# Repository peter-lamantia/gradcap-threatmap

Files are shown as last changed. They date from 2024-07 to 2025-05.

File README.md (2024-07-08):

# Graduation Cap Live Threat Map PCB

## About

This is a pet project to learn more about microcontroller development and PCB design.

My plan is to: 
1. Reverse engineer the Fortinet WebSocket API
2. Program an ESP32 to connect to said API and log messages to serial
3. Design a PCB with:
   - an ESP32-S3
   - a world map graphic and WS2812B LEDs placed at key cities
   - a lithium battery and charging circuit
   - dimensions that will place it neatly on a graduation cap
   - a display to show the attack details
4. Program the ESP32 to parse the incoming WebSocket such that:
   - the longitudinal data will map to the closest physical LED on the board
   - the LED will light up with a certain color depending on the threat type
   - ideally, I can make the LEDs animated in a cool way

## Roadmap
- WiFi connection reestablishment
- WebSocket connection reestablishment
- An actual PCB to mess around with. It may be useful to do this in revisions, e.g. make a PCB with the LEDs first, write the software for that, then make a more capable PCB with all components. After all, it is my first time doing this.
- Figure out how to actually debug (not just print program state to serial!)

## Changelog

### 2024-07-07
- Full migration to Platform.io (it's great!)
- Started printing out threats to an OLED display
   - Used the U8g2 library, specifically [u8log](https://github.com/olikraus/u8g2/wiki/u8logreference) for display output
   - Parsed the JSON sent from the WebSocket using [ArduinoJSON](https://arduinojson.org/)
- Added and did some testing with [FastLED](https://github.com/FastLED/FastLED), but have not implemented it yet (it is likely best to wait until I've made the PCB)

### 2024-06-29 (initial commit)
- WiFi connection establishment
- WebSocket connection to Fortinet
- Prints WebSocket messages to serial

## Known issues/fixes
- If serial is enabled, the XIAO ESP32-S3 will not allow reflashing. To fix this, hold the boot button while powering it on, and then flash at will!

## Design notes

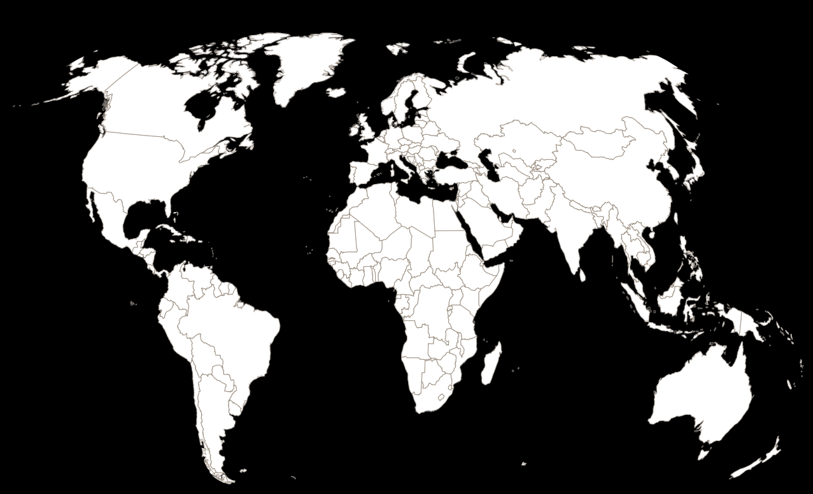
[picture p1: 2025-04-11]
pcb/winkel-tripel-no-antarctica.png

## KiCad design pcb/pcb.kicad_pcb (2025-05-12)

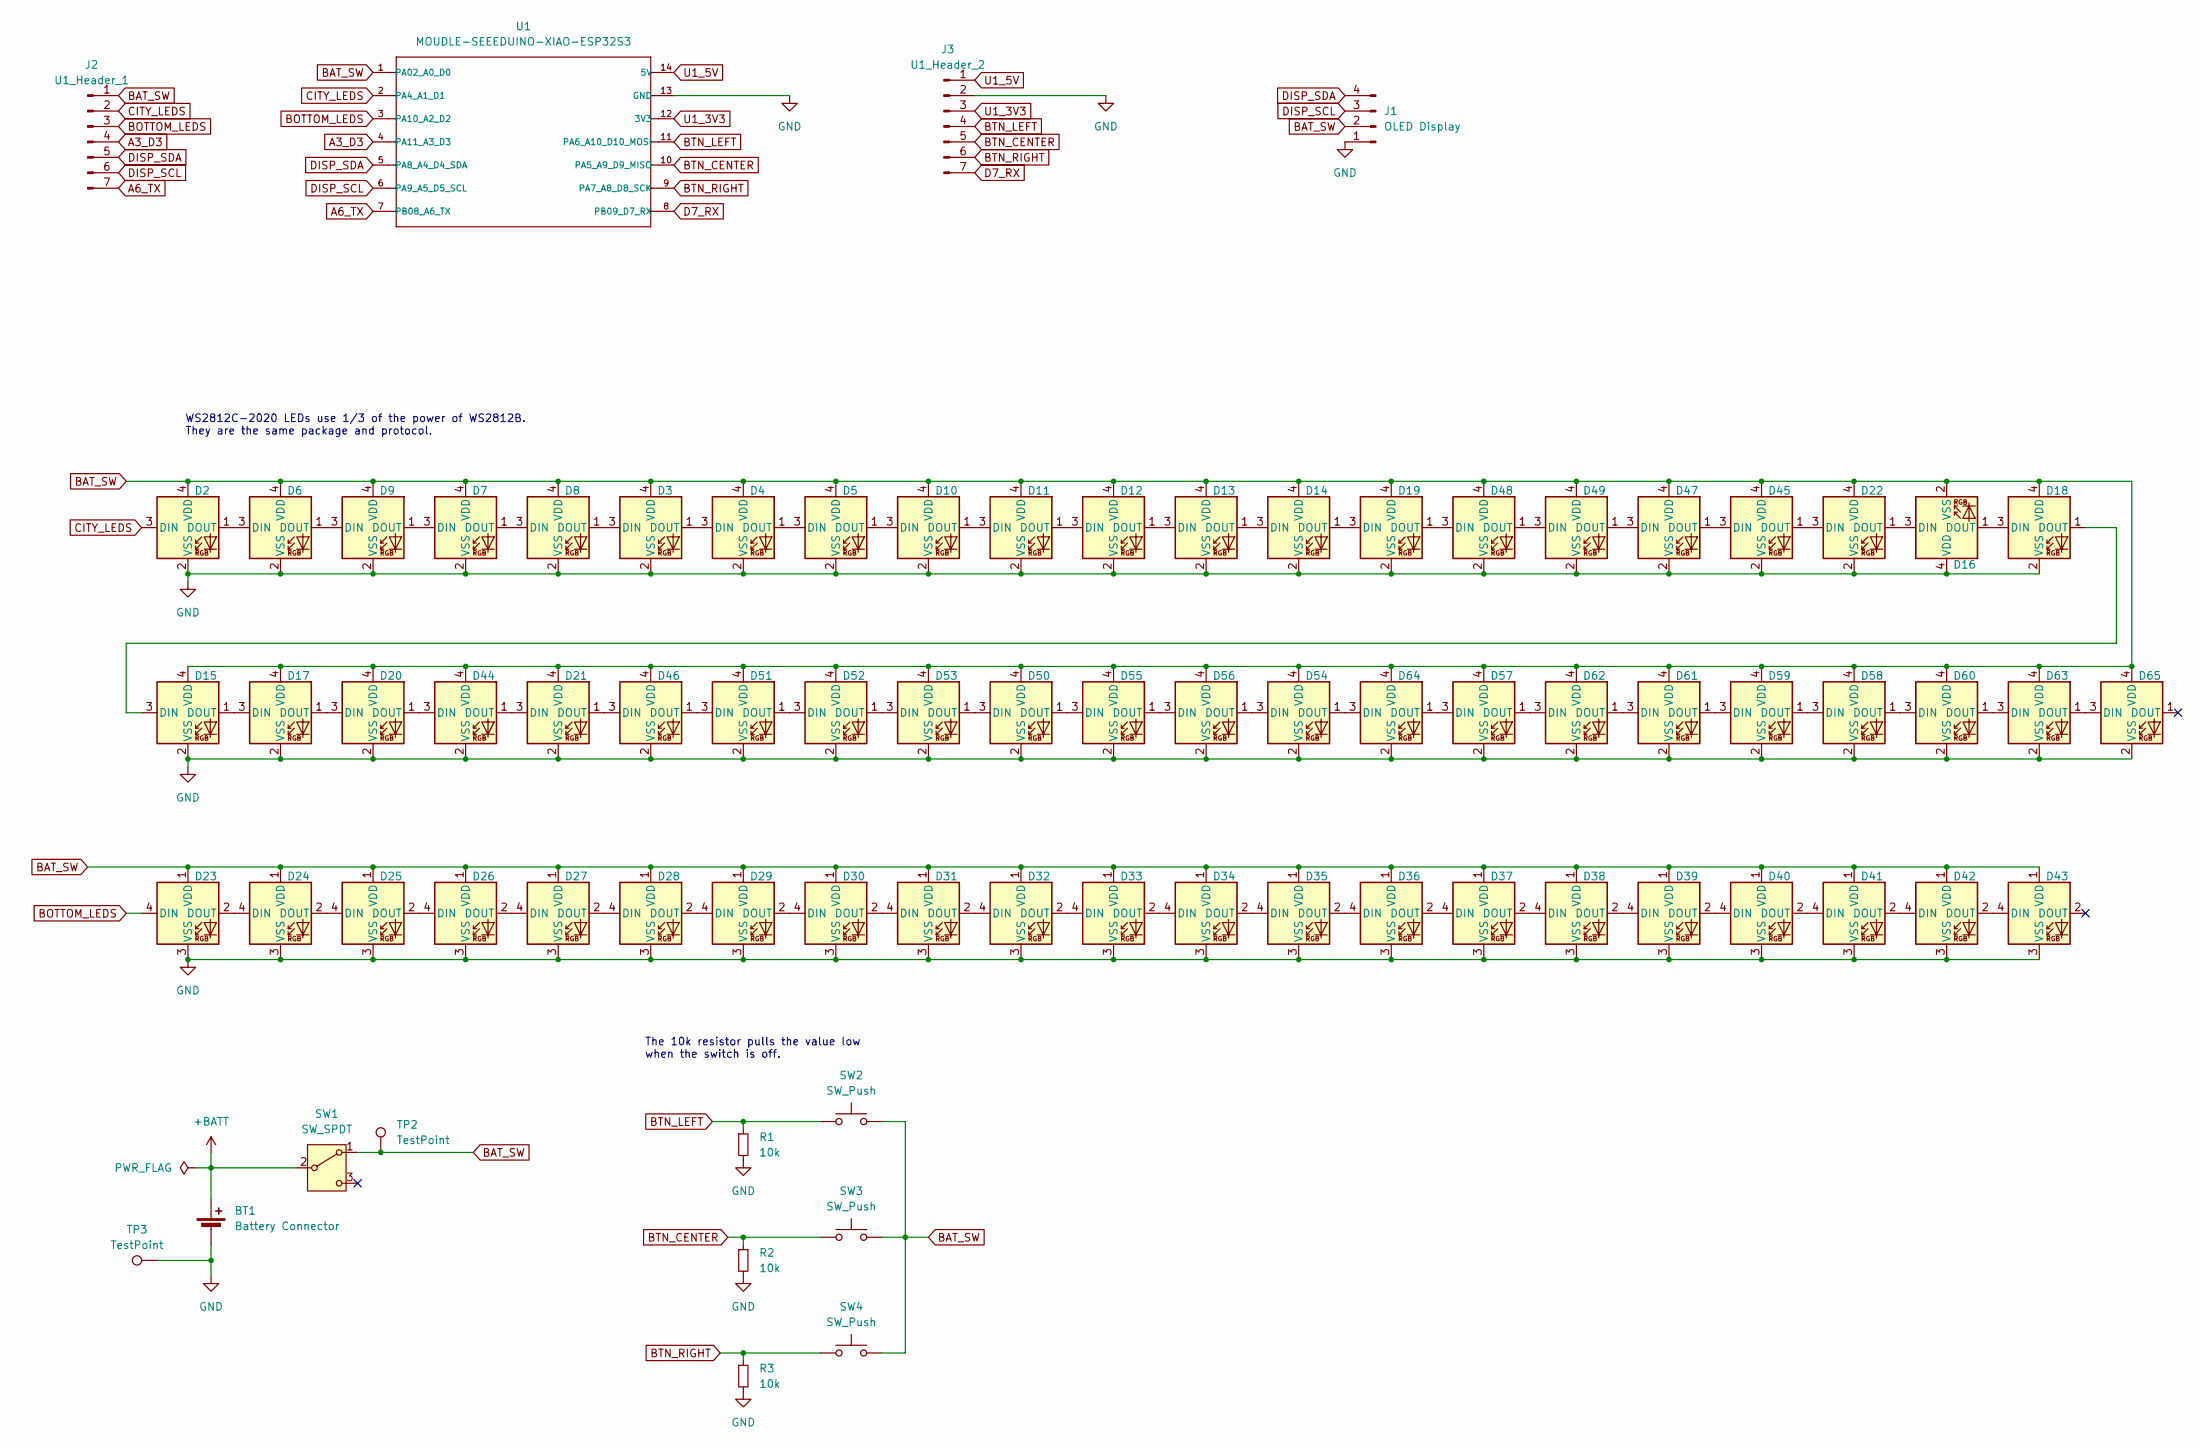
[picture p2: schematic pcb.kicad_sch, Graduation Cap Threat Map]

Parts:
BT1: Battery Connector; JST_PH_S2B-PH-K_1x02_P2.00mm_Horizontal
D2, D3, D4, D5, D6, D7, D8, D9, D10, D11, D12, D13, D14, D15, D16, D17, D18, D19, D20, D21, D22, D44, D45, D46, D47, D48, D49, D50, D51, D52, D53, D54, D55, D56, D57, D58, D59, D60, D61, D62, D63, D64, D65: WS2812C-2020; LED_WS2812B-2020_PLCC4_2.0x2.0mm
D23, D24, D25, D26, D27, D28, D29, D30, D31, D32, D33, D34, D35, D36, D37, D38, D39, D40, D41, D42, D43: WS2812C; LED_WS2812B_PLCC4_5.0x5.0mm_P3.2mm
J1: OLED Display; PinHeader_1x04_P2.54mm_Vertical
J2: U1_Header_1; PinSocket_1x07_P2.54mm_Vertical
J3: U1_Header_2; PinSocket_1x07_P2.54mm_Vertical
R1, R2, R3: 10k; R_Axial_DIN0207_L6.3mm_D2.5mm_P7.62mm_Horizontal
SW1: SW_SPDT; SW_Slide_SPDT_Angled_CK_OS102011MA1Q
SW2, SW3, SW4: SW_Push; SW_PUSH-12mm
TP2, TP3: TestPoint; TestPoint_Keystone_5015_Micro_Mini
U1: MOUDLE-SEEEDUINO-XIAO-ESP32S3; XIAO-ESP32S3-DIP

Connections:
+BATT: BT1.1 (+), SW1.2 (B)
A3_D3: J2.4, U1.4 (PA11_A3_D3)
A6_TX: J2.7, U1.7 (PB08_A6_TX)
BAT_SW: D2.4 (VDD), D3.4 (VDD), D4.4 (VDD), D5.4 (VDD), D6.4 (VDD), D7.4 (VDD), D8.4 (VDD), D9.4 (VDD), D10.4 (VDD), D11.4 (VDD), D12.4 (VDD), D13.4 (VDD), D14.4 (VDD), D15.4 (VDD), D16.2 (VSS), D17.4 (VDD), D18.4 (VDD), D19.4 (VDD), D20.4 (VDD), D21.4 (VDD), D22.4 (VDD), D23.1 (VDD), D24.1 (VDD), D25.1 (VDD), D26.1 (VDD), D27.1 (VDD), D28.1 (VDD), D29.1 (VDD), D30.1 (VDD), D31.1 (VDD), D32.1 (VDD), D33.1 (VDD), D34.1 (VDD), D35.1 (VDD), D36.1 (VDD), D37.1 (VDD), D38.1 (VDD), D39.1 (VDD), D40.1 (VDD), D41.1 (VDD), D42.1 (VDD), D43.1 (VDD), D44.4 (VDD), D45.4 (VDD), D46.4 (VDD), D47.4 (VDD), D48.4 (VDD), D49.4 (VDD), D50.4 (VDD), D51.4 (VDD), D52.4 (VDD), D53.4 (VDD), D54.4 (VDD), D55.4 (VDD), D56.4 (VDD), D57.4 (VDD), D58.4 (VDD), D59.4 (VDD), D60.4 (VDD), D61.4 (VDD), D62.4 (VDD), D63.4 (VDD), D64.4 (VDD), D65.4 (VDD), J1.2, J2.1, SW1.1 (A), SW2.2, SW3.2, SW4.2, TP2.1, U1.1 (PA02_A0_D0); also elsewhere on the board
BOTTOM_LEDS: D23.4 (DIN), J2.3, U1.3 (PA10_A2_D2)
BTN_CENTER: J3.5, R2.1, SW3.1, U1.10 (PA5_A9_D9_MISO)
BTN_LEFT: J3.4, R1.1, SW2.1, U1.11 (PA6_A10_D10_MOSI)
BTN_RIGHT: J3.6, R3.1, SW4.1, U1.9 (PA7_A8_D8_SCK)
CITY_LEDS: D2.3 (DIN), J2.2, U1.2 (PA4_A1_D1)
D7_RX: J3.7, U1.8 (PB09_D7_RX)
DISP_SCL: J1.3, J2.6, U1.6 (PA9_A5_D5_SCL)
DISP_SDA: J1.4, J2.5, U1.5 (PA8_A4_D4_SDA)
GND: BT1.2 (-), D2.2 (VSS), D3.2 (VSS), D4.2 (VSS), D5.2 (VSS), D6.2 (VSS), D7.2 (VSS), D8.2 (VSS), D9.2 (VSS), D10.2 (VSS), D11.2 (VSS), D12.2 (VSS), D13.2 (VSS), D14.2 (VSS), D15.2 (VSS), D16.4 (VDD), D17.2 (VSS), D18.2 (VSS), D19.2 (VSS), D20.2 (VSS), D21.2 (VSS), D22.2 (VSS), D23.3 (VSS), D24.3 (VSS), D25.3 (VSS), D26.3 (VSS), D27.3 (VSS), D28.3 (VSS), D29.3 (VSS), D30.3 (VSS), D31.3 (VSS), D32.3 (VSS), D33.3 (VSS), D34.3 (VSS), D35.3 (VSS), D36.3 (VSS), D37.3 (VSS), D38.3 (VSS), D39.3 (VSS), D40.3 (VSS), D41.3 (VSS), D42.3 (VSS), D43.3 (VSS), D44.2 (VSS), D45.2 (VSS), D46.2 (VSS), D47.2 (VSS), D48.2 (VSS), D49.2 (VSS), D50.2 (VSS), D51.2 (VSS), D52.2 (VSS), D53.2 (VSS), D54.2 (VSS), D55.2 (VSS), D56.2 (VSS), D57.2 (VSS), D58.2 (VSS), D59.2 (VSS), D60.2 (VSS), D61.2 (VSS), D62.2 (VSS), D63.2 (VSS), D64.2 (VSS), D65.2 (VSS), J1.1, J3.2, R1.2, R2.2, R3.2, TP3.1, U1.13 (GND); also elsewhere on the board
unnamed: D2.1 (DOUT), D6.3 (DIN)
unnamed: D3.3 (DIN), D8.1 (DOUT)
unnamed: D3.1 (DOUT), D4.3 (DIN)
unnamed: D4.1 (DOUT), D5.3 (DIN)
unnamed: D6.1 (DOUT), D9.3 (DIN)
unnamed: D7.3 (DIN), D9.1 (DOUT)
unnamed: D7.1 (DOUT), D8.3 (DIN)
unnamed: D5.1 (DOUT), D10.3 (DIN)
unnamed: D10.1 (DOUT), D11.3 (DIN)
unnamed: D11.1 (DOUT), D12.3 (DIN)
unnamed: D12.1 (DOUT), D13.3 (DIN)
unnamed: D13.1 (DOUT), D14.3 (DIN)
unnamed: D14.1 (DOUT), D19.3 (DIN)
unnamed: D15.3 (DIN), D18.1 (DOUT)
unnamed: D15.1 (DOUT), D17.3 (DIN)
unnamed: D16.3 (DIN), D22.1 (DOUT)
unnamed: D16.1 (DOUT), D18.3 (DIN)
unnamed: D17.1 (DOUT), D20.3 (DIN)
unnamed: D19.1 (DOUT), D48.3 (DIN)
unnamed: D20.1 (DOUT), D44.3 (DIN)
unnamed: D21.3 (DIN), D44.1 (DOUT)
unnamed: D21.1 (DOUT), D46.3 (DIN)
unnamed: D22.3 (DIN), D45.1 (DOUT)
unnamed: D23.2 (DOUT), D24.4 (DIN)
unnamed: D24.2 (DOUT), D25.4 (DIN)
unnamed: D25.2 (DOUT), D26.4 (DIN)
unnamed: D26.2 (DOUT), D27.4 (DIN)
unnamed: D27.2 (DOUT), D28.4 (DIN)
unnamed: D28.2 (DOUT), D29.4 (DIN)
unnamed: D29.2 (DOUT), D30.4 (DIN)
unnamed: D30.2 (DOUT), D31.4 (DIN)
unnamed: D31.2 (DOUT), D32.4 (DIN)
unnamed: D32.2 (DOUT), D33.4 (DIN)
unnamed: D33.2 (DOUT), D34.4 (DIN)
unnamed: D34.2 (DOUT), D35.4 (DIN)
unnamed: D35.2 (DOUT), D36.4 (DIN)
unnamed: D36.2 (DOUT), D37.4 (DIN)
unnamed: D37.2 (DOUT), D38.4 (DIN)
unnamed: D38.2 (DOUT), D39.4 (DIN)
unnamed: D39.2 (DOUT), D40.4 (DIN)
unnamed: D40.2 (DOUT), D41.4 (DIN)
unnamed: D41.2 (DOUT), D42.4 (DIN)
unnamed: D42.2 (DOUT), D43.4 (DIN)
unnamed: D45.3 (DIN), D47.1 (DOUT)
unnamed: D46.1 (DOUT), D51.3 (DIN)
unnamed: D47.3 (DIN), D49.1 (DOUT)
unnamed: D48.1 (DOUT), D49.3 (DIN)
unnamed: D50.3 (DIN), D53.1 (DOUT)
unnamed: D50.1 (DOUT), D55.3 (DIN)
unnamed: D51.1 (DOUT), D52.3 (DIN)
unnamed: D52.1 (DOUT), D53.3 (DIN)
unnamed: D54.3 (DIN), D56.1 (DOUT)
unnamed: D54.1 (DOUT), D64.3 (DIN)
unnamed: D55.1 (DOUT), D56.3 (DIN)
unnamed: D57.3 (DIN), D64.1 (DOUT)
unnamed: D57.1 (DOUT), D62.3 (DIN)
unnamed: D58.3 (DIN), D59.1 (DOUT)
unnamed: D58.1 (DOUT), D60.3 (DIN)
unnamed: D59.3 (DIN), D61.1 (DOUT)
unnamed: D60.1 (DOUT), D63.3 (DIN)
unnamed: D61.3 (DIN), D62.1 (DOUT)
unnamed: D63.1 (DOUT), D65.3 (DIN)
U1_3V3: J3.3, U1.12 (3V3)
U1_5V: J3.1, U1.14 (5V)

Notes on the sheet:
WS2812C-2020 LEDs use 1/3 of the power of WS2812B. They are the same package and protocol.
The 10k resistor pulls the value low when the switch is off.

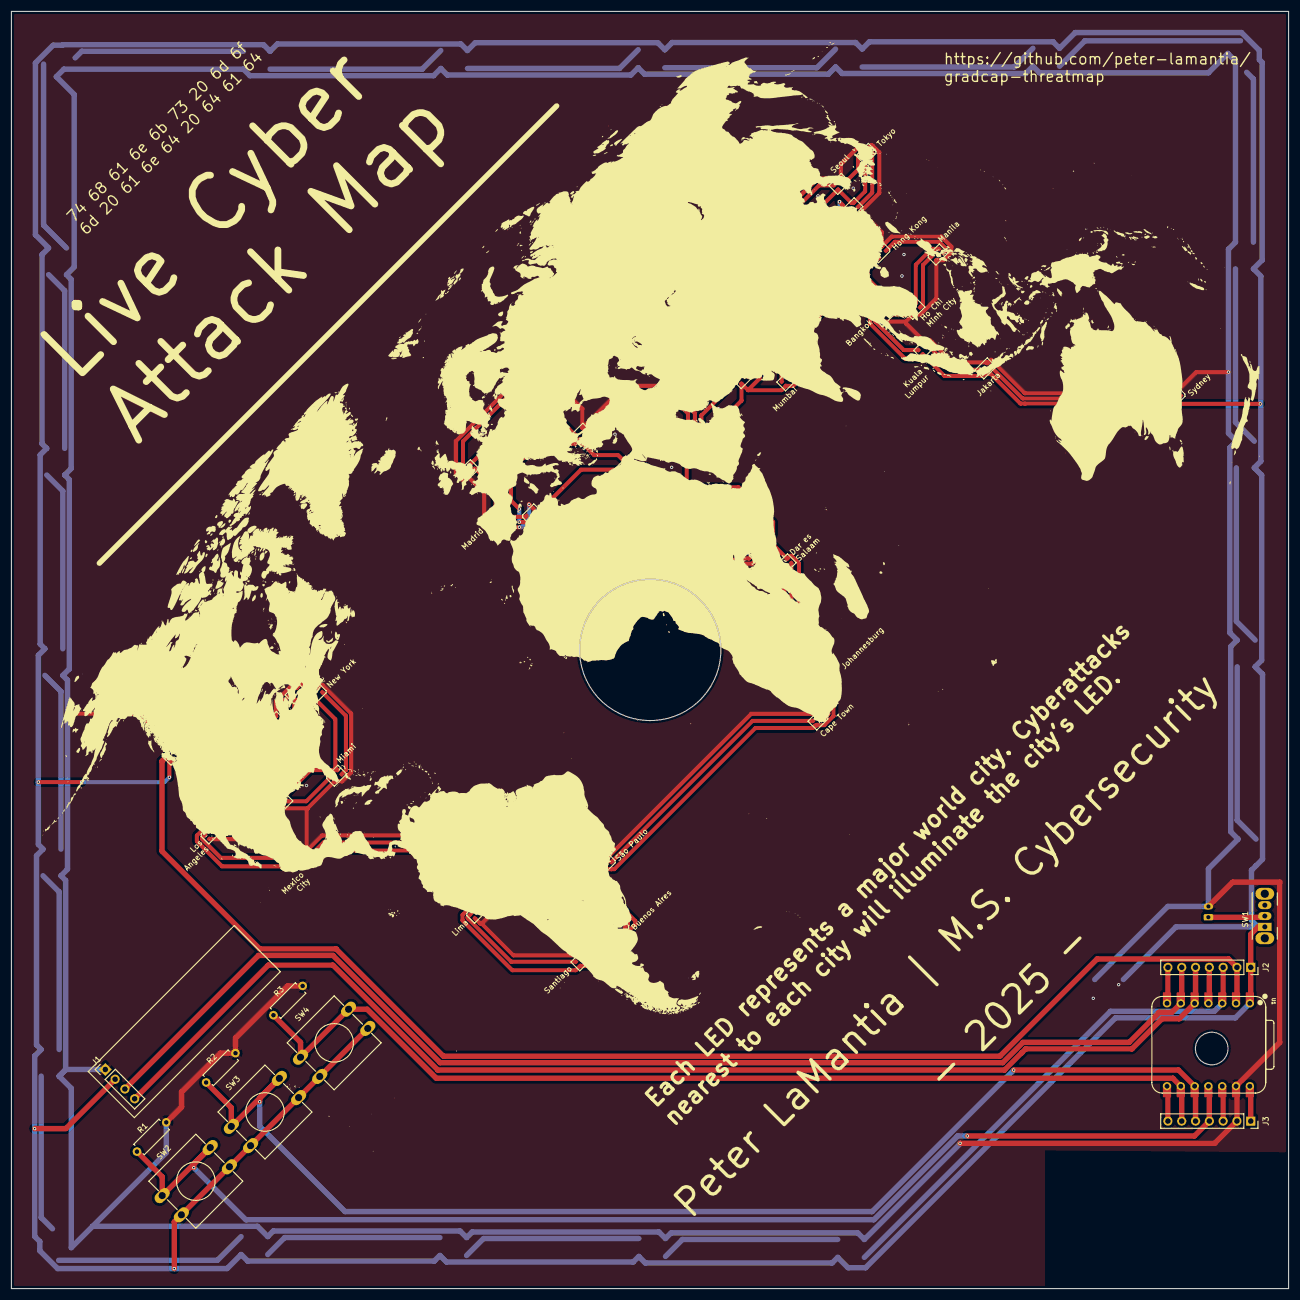
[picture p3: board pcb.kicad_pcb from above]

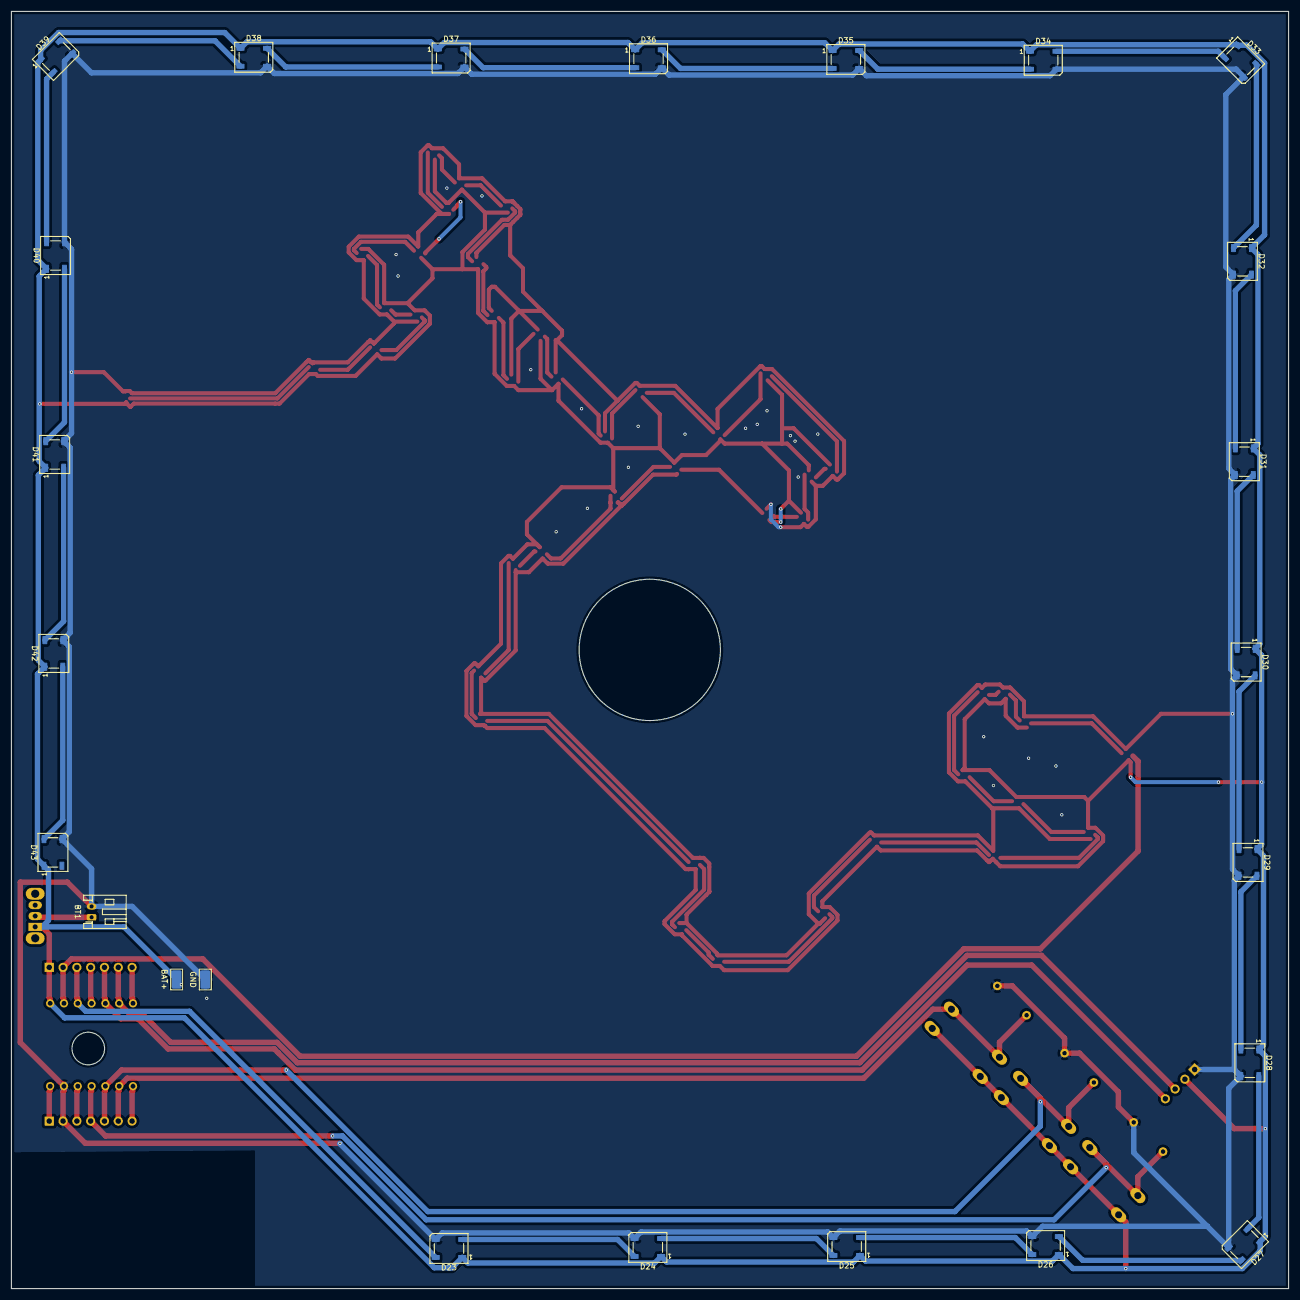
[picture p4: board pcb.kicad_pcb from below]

Board: 2 copper layers, 235.0 x 235.0 mm, 78 parts (24 on the bottom side), 77 nets.

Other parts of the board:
BAT+: TestPoint; TestPoint_Keystone_5015_Micro_Mini
GND: TestPoint; TestPoint_Keystone_5015_Micro_Mini

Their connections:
BAT_SW: BAT+.1; also elsewhere on the board
GND: GND.1; also elsewhere on the board

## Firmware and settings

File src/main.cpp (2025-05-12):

/**
By Peter LaMantia

Built using: 
  Arduino Websockets - https://github.com/gilmaimon/ArduinoWebsockets/
  Fortinet ThreatMap - https://threatmap.fortiguard.com/
  FastLED - https://github.com/FastLED/FastLED
  U8g2 - https://github.com/olikraus/u8g2
  ArduinoJson - https://arduinojson.org/
*/


#include <Arduino.h>
#include <WiFi.h>
#include <ArduinoWebsockets.h>
#include <FastLED.h>
#include <U8g2lib.h>
#include <Wire.h>
#include <ArduinoJson.h>

#include <secrets.h>


typedef struct {
  double latitude;
  double longitude;
} Location;

Location cities[] = {
  {49.2827, -123.1207}, // Vancouver
  {41.8781, -87.6298},  // Chicago
  {43.6511, -79.3837},  // Toronto
  {40.7128, -74.0060},  // New York
  {25.7617, -80.1918},  // Miami
  {29.7604, -95.3698},  // Houston
  {34.0522, -118.2437}, // Los Angeles
  {19.4326, -99.1332},  // Mexico City
  {4.7110, -74.0721},   // Bogota
  {-12.0464, -77.0428}, // Lima
  {-33.4489, -70.6693}, // Santiago
  {-34.6037, -58.3816}, // Buenos Aires
  {-23.5505, -46.6333}, // Sao Paulo
  {-33.9249, 18.4241},  // Cape Town
  {-26.2041, 28.0473},  // Johannesburg
  {-1.2921, 36.8219},   // Nairobi
  {15.5007, 32.5599},   // Khartoum
  {30.0444, 31.2357},   // Cairo
  {40.4168, -3.7038},   // Madrid
  {48.8566, 2.3522},    // Paris
  {51.5074, -0.1278},   // London
  {55.7558, 37.6173},   // Moscow
  {41.0082, 28.9784},   // Istanbul
  {35.6892, 51.3890},   // Tehran
  {24.7136, 46.6753},   // Riyadh
  {24.8607, 67.0011},   // Karachi
  {28.6139, 77.2090},   // Delhi
  {19.0760, 72.8777},   // Mumbai
  {23.8103, 90.4125},   // Dhaka
  {29.5630, 106.5516},  // Chongqing
  {39.9042, 116.4074},  // Beijing
  {37.5665, 126.9780},  // Seoul
  {35.6762, 139.6503},  // Tokyo
  {31.2304, 121.4737},  // Shanghai
  {22.3193, 114.1694},  // Hong Kong
  {14.5995, 120.9842},  // Manila
  {10.8231, 106.6297},  // Ho Chi Minh City
  {13.7563, 100.5018},  // Bangkok
  {3.1390, 101.6869},   // Kuala Lumpur
  {-6.2088, 106.8456},  // Jakarta
  {-33.8688, 151.2093}  // Sydney
};

// display setup
// U8X8_SSD1306_128X64_NONAME_HW_I2C u8x8(/* clock=*/ SCL, /* data=*/ SDA, /* reset=*/ U8X8_PIN_NONE);   // OLEDs without Reset of the Display
// U8X8LOG u8x8log;
// #define U8LOG_WIDTH 16
// #define U8LOG_HEIGHT 8
// uint8_t u8log_buffer[U8LOG_WIDTH*U8LOG_HEIGHT];

// websockets config
const char* websockets_server = "ws://threatmap.fortiguard.com:80/ws";  //server adress and port
const char* init_msg_1 = "[1,\"threatmap\",{\"roles\":{\"caller\":{\"features\":{\"caller_identification\":true,\"progressive_call_results\":true}},\"callee\":{\"features\":{\"caller_identification\":true,\"pattern_based_registration\":true,\"shared_registration\":true,\"progressive_call_results\":true,\"registration_revocation\":true}},\"publisher\":{\"features\":{\"publisher_identification\":true,\"subscriber_blackwhite_listing\":true,\"publisher_exclusion\":true}},\"subscriber\":{\"features\":{\"publisher_identification\":true,\"pattern_based_subscription\":true,\"subscription_revocation\":true}}}}]";
const char* init_msg_2 = "[32,8256555849692380,{},\"ips\"]";
using namespace websockets;
WebsocketsClient client;

JsonDocument doc;


void onMessageCallback(WebsocketsMessage message) {
  Serial.print("Got Message: ");
  Serial.println(message.data());

  // attempt JSON deserialization
  deserializeJson(doc, message.data());
  const char* threat = doc[4][0]["type"];
  Serial.println("Deserialized JSON: ");
  Serial.println(threat);

  // get src and dest countrycode
  const char* src_country = doc[4][0]["src"]["countrycode"];
  const char* dst_country = doc[4][0]["dst"]["countrycode"];

  // get severity
  const char* severity = doc[4][0]["severity"];

  // // print the threat
  // u8x8log.setRedrawMode(0);		// 0: Update screen with newline, 1: Update screen for every char
  // u8x8log.print("\f");
  // u8x8log.print("Source: ");
  // u8x8log.print(src_country);
  // u8x8log.print("\n");
  // u8x8log.print("Dest:   ");
  // u8x8log.print(dst_country);
  // u8x8log.print("\n\n");
  // u8x8log.print("Severity: \n ");
  // u8x8log.print(severity);
  // u8x8log.print("\n\n");
  // delay(500);

  // u8x8log.print("Threat: ");
  // u8x8log.setRedrawMode(1);		// 0: Update screen with newline, 1: Update screen for every char
  // u8x8log.print(threat);
  // u8x8log.print("\n");
  // delay(1500);
}


void onEventsCallback(WebsocketsEvent event, String data) {
  if (event == WebsocketsEvent::ConnectionOpened) {
    Serial.println("Connnection Opened");
  } else if (event == WebsocketsEvent::ConnectionClosed) {
    Serial.println("Connnection Closed");
  } else if (event == WebsocketsEvent::GotPing) {
    Serial.println("Got a Ping!");
  } else if (event == WebsocketsEvent::GotPong) {
    Serial.println("Got a Pong!");
  }
}


void setup() {
  pinMode(LED_BUILTIN, OUTPUT);
  digitalWrite(LED_BUILTIN, HIGH); // set LED off (high is off on XIAO ESP32-S3)

  // set up display
  // u8x8.begin();
  // u8x8.setFont(u8x8_font_victoriamedium8_r);
  // u8x8log.begin(u8x8, U8LOG_WIDTH, U8LOG_HEIGHT, u8log_buffer);
  // u8x8log.setRedrawMode(1);		// 0: Update screen with newline, 1: Update screen for every char
  // u8x8log.print("Starting up...");

  // wait a moment before beginning serial
  delay(2000);
  Serial.begin(115200);
  // Serial.print("\nStarting up...");

  // Connect to wifi
  WiFi.begin(WIFI_SSID, WIFI_PASSWORD);

  // Wait some time to connect to WiFi
  for (int i = 0; i < 10 && WiFi.status() != WL_CONNECTED; i++) {
    Serial.print(".");
    // u8x8log.print(".");
    delay(1000);
  }
  if (WiFi.status() != WL_CONNECTED) {
    Serial.println("\n\nERROR: Failed to connect to WiFi.");
    // u8x8log.println("\n\nERROR: Failed to connect to WiFi.");
    digitalWrite(LED_BUILTIN, LOW); // set led ON for error
    while (true) {} // wait forever
  }
  Serial.print("\n\nWiFi connected.\n\n");
  // u8x8log.print("\n\nWiFi connected.\n\n");

  // Setup Callbacks
  client.onMessage(onMessageCallback);
  client.onEvent(onEventsCallback);

  // add header
  client.addHeader("Sec-WebSocket-Protocol", "wamp.2.json");

  // Connect to server
  if (client.connect(websockets_server)) {
    // initial setup to begin receiving messages
    client.send(init_msg_1);
    client.send(init_msg_2);
  }
  else {
    Serial.println("ERROR: Failed to connect to WebSocket server.");
    // u8x8log.println("ERROR: Failed to connect to WebSocket server.");
    digitalWrite(LED_BUILTIN, LOW); // set led ON for error
    Serial.end();
    while (true) {} // wait forever
  }  
}


void loop() {
  client.poll();
}

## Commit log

2025-04-11 It's crunch time
    This probably has more files than I am supposed to commit to VCS
    [pcb.kicad_pcb, pcb.kicad_sch]
2025-04-15 Moving along
    [pcb.kicad_pcb, pcb.kicad_sch]
2025-04-16 Almost there
    [pcb.kicad_pcb, pcb.kicad_sch]
2025-05-12 Updated pcb
    [pcb.kicad_pcb, pcb.kicad_sch]
